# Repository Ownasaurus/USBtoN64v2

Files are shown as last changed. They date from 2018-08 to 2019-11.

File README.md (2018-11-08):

# USBtoN64v2
Utilizes STM32F446 on a Nucleo-F446RE with custom header or on a fully custom board for usb and n64 communication.

In this repository, you can find the latest version of the source code (TrueSTUDIO), 3D case (.stl), and PCB (Eagle .brd and .sch) files.

Currently supported USB devices:
- Keyboard
- Dualshock 3 Sixaxis
- Dualshock 4 v1 (with help from Kazon Wilson [kwilson21]) and v2
- Wireless Xbox 360 with Microsoft USB wireless receiver
- Wired Xbox 360
- Wired Xbox One

## Setting the controls:
1) Press the blue button on the Nucleo or the only button on the custom PCB. A new green LED (light) should light up solid when you go into "set controls" mode, and it should turn off when you finish setting the controls correctly.
2) Press the buttons in the appropriate order depending on which device is plugged in. For Xbox and PS, you also need to set range and deadzone. Please see below for instructions.
3) (optional) Press the same button again at any time to exit “set controls” mode early if you make a mistake.

### Xbox / Playstation:
DPAD_UP, DPAD_DOWN, DPAD_LEFT, DPAD_RIGHT, BUTTON_START, BUTTON_B, BUTTON_A, C_UP, C_DOWN, C_LEFT, C_RIGHT, BUTTON_L, BUTTON_R, BUTTON_Z

Next you set your RANGE. It starts at 100 by default.
Up (+) and Down (-) on the D-pad will increase or decrease the range by 5.
Right (+) and Left (-) on the D-pad will increase or decrease the range by 1.
The range cannot be greater than 100 or less than 0.
When you are done, hit "A" on the Xbox controller or "X" on the Playstation controller to move on.

Next you set your DEADZONE. It starts at 20 by default.
Up (+) and Down (-) on the D-pad will increase or decrease the deadzone by 5.
Right (+) and Left (-) on the D-pad will increase or decrease the deadzone by 1.
The deadzone cannot be greater than 100 or less than 0.
When you are done, hit "A" on the Xbox controller or "X" on the Playstation controller. Congratulations, you are done configuring your controls!

### KB:
A_UP, A_DOWN, A_LEFT, A_RIGHT, DPAD_UP, DPAD_DOWN, DPAD_LEFT, DPAD_RIGHT, BUTTON_START, BUTTON_B, BUTTON_A, C_UP, C_DOWN, C_LEFT, C_RIGHT, BUTTON_L, BUTTON_R, BUTTON_Z

Note that the device saves the controls even when the device is powered off. It saves the Xbox and Playstation controls together as a shared layout and the Keyboard controls separately.

## Updating the firmware:

### Nucleo (Prototype consisting of 2 connected boards)
Plug the device into a PC with a USB mini B cable, and drag&drop a .bin firmware file.

### v2 (one board in a case distributed only after 09/2018)
The v2 has a switch with two possible positions: "ON" or "1" (which is qutie confusing if you ask me).
- *The switch should be set to "1" for normal operation.*
- *The switch should be set to "ON" for firmware upgrade.*
- *The switch should be never be flipped while the device is powered to "ON" for firmware upgrade.*

So, first fip the switch to "ON". Plug the device into a PC with a USB mini B cable, and it should show up as a USB DFU device.
Use the "DfuSeDemo" software provided by STMicroelectronics to update the firmware with a .dfu file.
The "Dfu file manager" software is also provided alongside the "DfuSeDemo" by STMicroelectronics.
Then, unplug the device from the PC. Finally, flip the switch back "1".

## TODO:
- Complete LED support for PS4 (currently non-functional)
- Re-design PCB (and case) to be significantly smaller (in progress)

## Currently known bugs:
- None!

By: Ownasaurus

## Special thanks to:
????? ????? [Rainshifter] for help and support along the whole process

Kazon Wilson [kwilson21] for help with Dualshock 4 support

???? ????? [Serisium] for help with PCB design and understanding the STM32 hardware

Jeff Longo [?????] for help with PCB design and 3D case design

# Gamecube support - ALPHA
Gamecube support is currently in the experimental phase.
- If the data line and ground lines of a Gamecube cable are connected to the adapter, it should function.
- If BOTH N64 and Gamecube cables are attached, the device should be able to automatically detect which console is being used. The unused cable MUST be unplugged for proper functionality.
- Only XBOX controllers are currently supported.
- The controls are currently static and mimic the Gamecube controller layout.
- The sensitivity and deadzone are "borrowed" from the N64 controller settings.
- GC(X) / XBOX(B) button is currently un-mapped due to Rainshifter's preferences for bug testing.

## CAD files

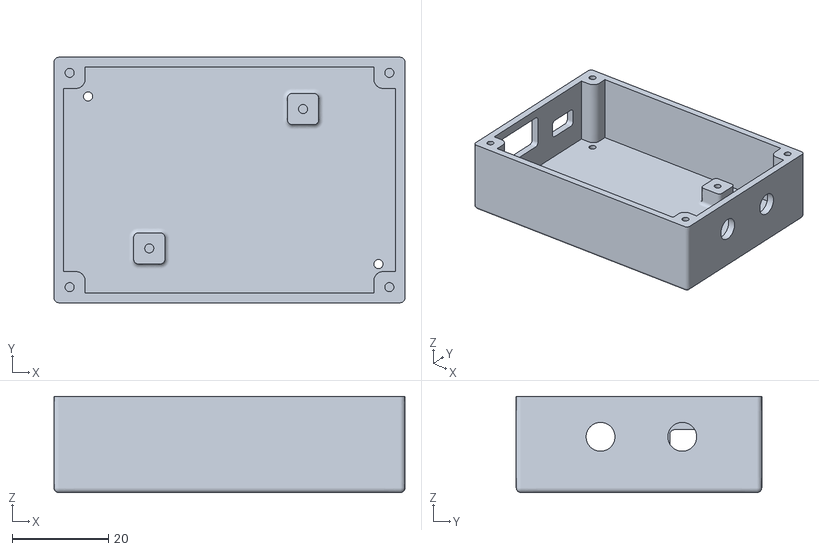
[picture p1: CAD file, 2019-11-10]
Custom Board/3D Case/small_bottom_case.stl
73.0 x 51.1 x 20.0

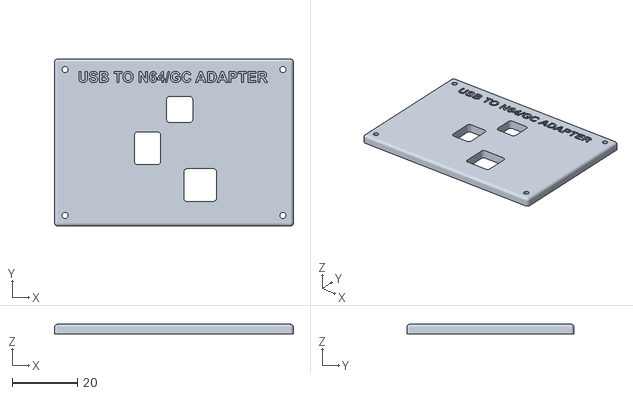
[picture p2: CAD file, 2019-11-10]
Custom Board/3D Case/small_top_case.stl
73.0 x 51.1 x 3.00

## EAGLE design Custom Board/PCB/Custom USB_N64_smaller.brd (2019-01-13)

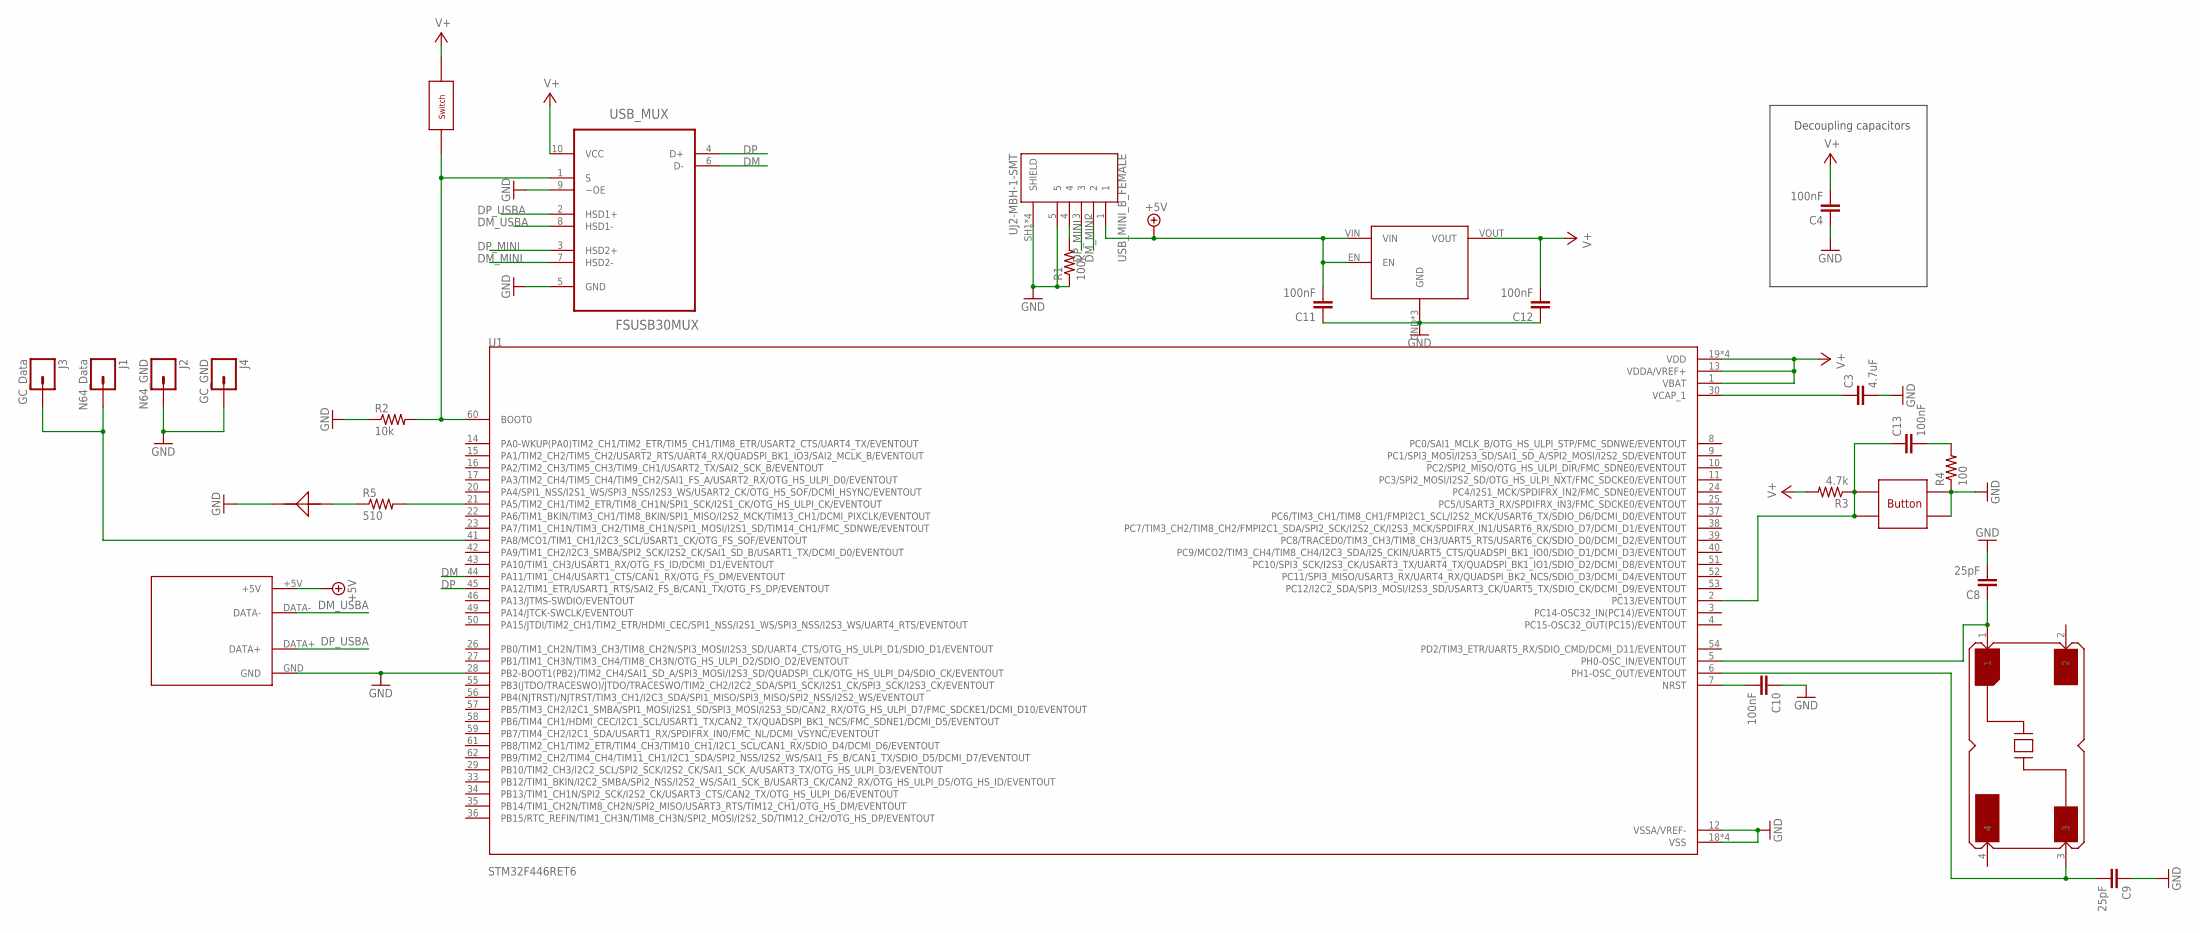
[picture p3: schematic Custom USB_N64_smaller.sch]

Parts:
C3: 4.7uF; C0805
C4, C10, C11, C12, C13: 100nF; C0805
C8, C9: 25pF; C0805
CHANGE_CONTROLS: PUSHBUTTON
J1: N64_Data; 1X01
J2: N64_GND; 1X01
J3: GC_Data; 1X01
J4: GC_GND; 1X01
R1: 100k; R0805
R2: 10k; R0805
R3: 4.7k; R0805
R4: 100; R0805
R5: 510; R0805
SWITCH: DM01
U1: STM32F446RET6; QFP50P1200X1200X160-64N
U$6: 17-21SYGC/S530-E2/TR8
USB_A_FEMALE: USB_A_F
USB_MINI_B_FEMALE: UJ2-MBH-1-SMT; CUI_UJ2-MBH-1-SMT
USB_MUX: FSUSB30MUX; SOP50P490X110-10N
V_REG: S-1172B33-U5T1G
XTAL_HSE: ABMM-8.000MHZ-B2-T; DFN-4

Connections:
3V3: C4.2, C12.2, R3.2, SWITCH.P$1, U1.1 (VBAT), U1.13 (VDDA/VREF+), U1.19 (VDD), U1.32 (VDD), U1.48 (VDD), U1.64 (VDD), USB_MUX.10 (VCC), V_REG.VOUT
+5V: C11.2, USB_A_FEMALE.+5V, USB_MINI_B_FEMALE.1, V_REG.EN, V_REG.VIN
DM: U1.44 (PA11/TIM1_CH4/USART1_CTS/CAN1_RX/OTG_FS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), USB_MUX.6 (D-)
DM_MINI: USB_MINI_B_FEMALE.2, USB_MUX.7 (HSD2-)
DM_USBA: USB_A_FEMALE.DATA-, USB_MUX.8 (HSD1-)
DP: U1.45 (PA12/TIM1_ETR/USART1_RTS/SAI2_FS_B/CAN1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), USB_MUX.4 (D+)
DP_MINI: USB_MINI_B_FEMALE.3, USB_MUX.3 (HSD2+)
DP_USBA: USB_A_FEMALE.DATA+, USB_MUX.2 (HSD1+)
GND: C3.2, C4.1, C8.2, C9.1, C10.1, C11.1, C12.1, CHANGE_CONTROLS.P$3, CHANGE_CONTROLS.P$4, J2.1, J4.1, R1.1, R2.1, R4.1, U1.12 (VSSA/VREF-), U1.18 (VSS), U1.28 (PB2-BOOT1(PB2)/TIM2_CH4/SAI1_SD_A/SPI3_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), U1.31 (VSS), U1.47 (VSS), U1.63 (VSS), U$6.NEG, USB_A_FEMALE.GND, USB_MINI_B_FEMALE.5, USB_MINI_B_FEMALE.SH1 (SHIELD), USB_MINI_B_FEMALE.SH2 (SHIELD), USB_MINI_B_FEMALE.SH3 (SHIELD), USB_MINI_B_FEMALE.SH4 (SHIELD), USB_MUX.5 (GND), USB_MUX.9 (~OE), V_REG.GND, V_REG.GND2 (GND), V_REG.GND3 (GND)
unnamed: R2.2, SWITCH.P$2, U1.60 (BOOT0), USB_MUX.1 (S)
unnamed: C10.2, U1.7 (NRST)
unnamed: C8.1, U1.5 (PH0-OSC_IN/EVENTOUT), XTAL_HSE.1
unnamed: C3.1, U1.30 (VCAP_1)
unnamed: C9.2, U1.6 (PH1-OSC_OUT/EVENTOUT), XTAL_HSE.3
unnamed: J1.1, J3.1, U1.41 (PA8/MCO1/TIM1_CH1/I2C3_SCL/USART1_CK/OT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)
unnamed: C13.1, CHANGE_CONTROLS.P$1, CHANGE_CONTROLS.P$2, R3.1, U1.2 (PC13/EVENTOUT)
unnamed: R5.2, U1.21 (PA5/TIM2_CH1/TIM2_ETR/TIM8_CH1N/SPI1_SC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)
unnamed: C13.2, R4.2
unnamed: R5.1, U$6.POS
unnamed: R1.2, USB_MINI_B_FEMALE.4

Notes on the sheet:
Decoupling capacitors

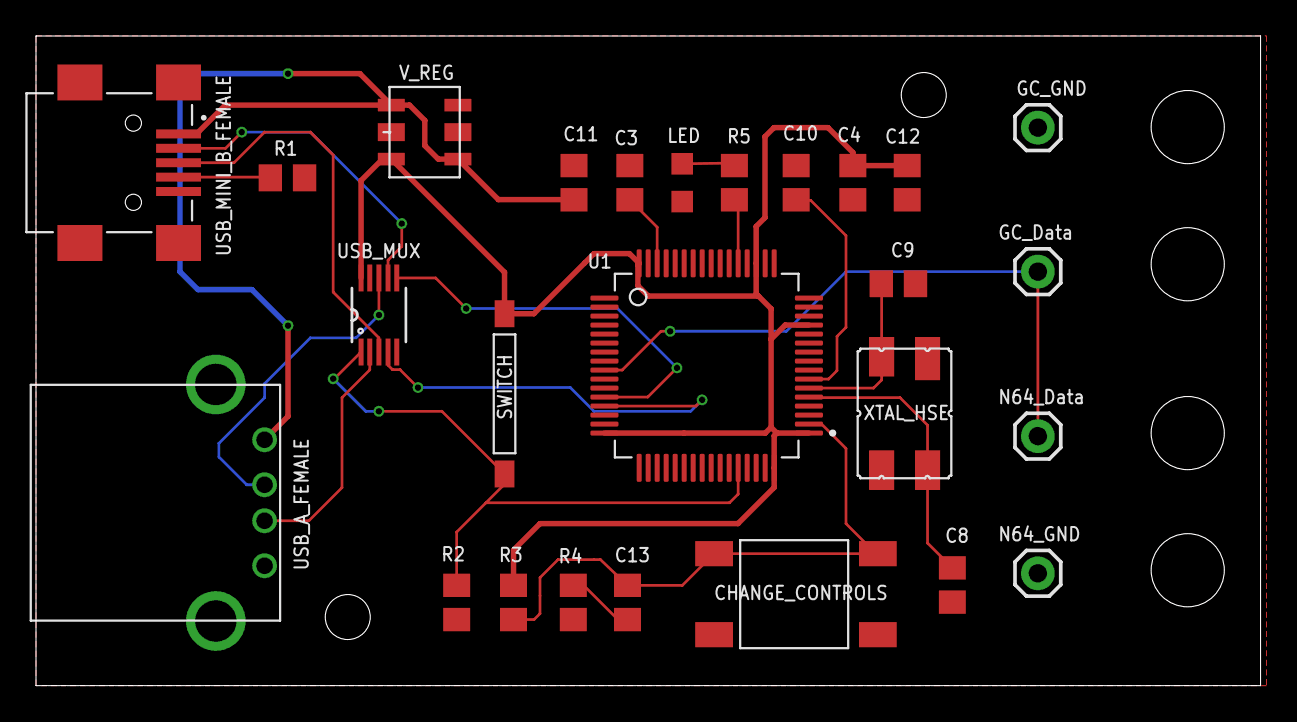
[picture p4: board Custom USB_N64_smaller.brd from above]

Board: 2 copper layers, 68.0 x 36.1 mm, 26 parts (0 on the bottom side), 20 nets.

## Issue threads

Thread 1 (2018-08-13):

Microsoft Wireless Xbox 360 randomly freezes and drops inputs

Ownasaurus, 2018-08-13:
Confirmed on 2 separate setups with 2 sets of hardware. Cause is currently unknown. Would LOVE a fix for this as it is the last major issue.

Ownasaurus, 2018-08-16:
Resolved in commit #25948df

Closed 2018-08-16.

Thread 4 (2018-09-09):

PS4 LED Support

Ownasaurus, 2018-09-09:
Not working yet. There's some code in there for it though.

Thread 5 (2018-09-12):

Add instructions on how to update the firmware

Ownasaurus, 2018-09-12:
Ensure to explain both the Nucelo process (drag&drop bin) and the custom PCB process (flip switch and DfuSe software)

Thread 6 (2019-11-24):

BUG: Setting N64 KB Controls

Ownasaurus, 2019-11-24:
After pressing the "set controls" button, It seems to sometimes ignore first button pressed, leading to an off-by-one when setting the controls.

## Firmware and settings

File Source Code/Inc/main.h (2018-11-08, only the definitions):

#define B1_Pin GPIO_PIN_13
#define B1_GPIO_Port GPIOC
#define USART_TX_Pin GPIO_PIN_2
#define USART_TX_GPIO_Port GPIOA
#define USART_RX_Pin GPIO_PIN_3
#define USART_RX_GPIO_Port GPIOA
#define LD2_Pin GPIO_PIN_5
#define LD2_GPIO_Port GPIOA
#define N64_DATA_Pin GPIO_PIN_8
#define N64_DATA_GPIO_Port GPIOA
#define N64_DATA_EXTI_IRQn EXTI9_5_IRQn
#define TMS_Pin GPIO_PIN_13
#define TMS_GPIO_Port GPIOA
#define TCK_Pin GPIO_PIN_14
#define TCK_GPIO_Port GPIOA
#define SWO_Pin GPIO_PIN_3
#define SWO_GPIO_Port GPIOB
#define tN 0.03921568627f //(10/255)
#define DEFAULT_RANGE 100
#define DEFAULT_DEADZONE 20
#define TRIGGER_THRESHOLD 5
#define XPAD_MAX 32767 // -32768 to +32767...
#define DS3_MAX 127

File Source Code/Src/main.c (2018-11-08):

// Ownasaurus
// rawr

/**
  ******************************************************************************
  * @file           : main.c
  * @brief          : Main program body
  ******************************************************************************
  * This notice applies to any and all portions of this file
  * that are not between comment pairs USER CODE BEGIN and
  * USER CODE END. Other portions of this file, whether 
  * inserted by the user or by software development tools
  * are owned by their respective copyright owners.
  *
  * Copyright (c) 2018 STMicroelectronics International N.V. 
  * All rights reserved.
  *
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
  ******************************************************************************
  */
/* Includes ------------------------------------------------------------------*/
#include "main.h"
#include "stm32f4xx_hal.h"
#include "stm32f4xx_hal_flash.h"
#include "stm32f4xx_hal_flash_ex.h"
#include "usb_host.h"

/* USER CODE BEGIN Includes */
#include <string.h>
#include "usbh_hid_ds3.h"

/* USER CODE END Includes */

UART_HandleTypeDef huart2;
uint8_t state = NORMAL;
#define SAVE_ADDR 0x08010000 // sector 4
Controls controls;
Controls* saveData = (Controls*)SAVE_ADDR;
uint8_t blueButtonPressed = 0;
ControllerType type = CONTROLLER_NONE;

/* USER CODE BEGIN PV */
N64ControllerData n64_data;
GCControllerData gc_data;
/* USER CODE END PV */

void SystemClock_Config(void);
static void MX_GPIO_Init(void);
static void MX_USART2_UART_Init(void);
void MX_USB_HOST_Process(void);

/* USER CODE BEGIN PFP */
void my_wait_us_asm(int n);

/* USER CODE END PFP */

/* USER CODE BEGIN 0 */

void ChangeButtonMappingKB(uint8_t bt)
{
    if(state == A_UP) // state = 1 --> analog up
    {
        controls.KBControls.KEYBOARD_a_up = bt;
    }
    else if(state == A_DOWN) // state = 2 --> analog up
    {
        controls.KBControls.KEYBOARD_a_down = bt;
    }
    else if(state == A_LEFT) // state = 3 --> analog up
    {
        controls.KBControls.KEYBOARD_a_left = bt;
    }
    else if(state == A_RIGHT) // state = 4 --> analog up
    {
        controls.KBControls.KEYBOARD_a_right = bt;
    }
    else if(state == DPAD_UP) // state = 5 --> dpad up
    {
        controls.KBControls.KEYBOARD_d_up = bt;
    }
    else if(state == DPAD_DOWN) // state = 6 --> dpad down
    {
        controls.KBControls.KEYBOARD_d_down = bt;
    }
    else if(state == DPAD_LEFT) // state = 7 --> dpad left
    {
        controls.KBControls.KEYBOARD_d_left = bt;
    }
    else if(state == DPAD_RIGHT) // state = 8 --> dpad right
    {
        controls.KBControls.KEYBOARD_d_right = bt;
    }
    else if(state == BUTTON_START) // state = 9 --> start
    {
        controls.KBControls.KEYBOARD_start = bt;
    }
    else if(state == BUTTON_B) // state = 10 --> B
    {
        controls.KBControls.KEYBOARD_b = bt;
    }
    else if(state == BUTTON_A) // state = 11 --> A
    {
        controls.KBControls.KEYBOARD_a = bt;
    }
    else if(state == C_UP) // state = 12 --> c up
    {
        controls.KBControls.KEYBOARD_c_up = bt;
    }
    else if(state == C_DOWN) // state = 13 --> c down
    {
        controls.KBControls.KEYBOARD_c_down = bt;
    }
    else if(state == C_LEFT) // state = 14 --> c left
    {
        controls.KBControls.KEYBOARD_c_left = bt;
    }
    else if(state == C_RIGHT) // state = 15 --> c right
    {
        controls.KBControls.KEYBOARD_c_right = bt;
    }
    else if(state == BUTTON_L) // state = 16 --> L
    {
        controls.KBControls.KEYBOARD_l = bt;
    }
    else if(state == BUTTON_R) // state = 17 --> R
    {
        controls.KBControls.KEYBOARD_r = bt;
    }
    else if(state == BUTTON_Z) // state = 18 --> Z
    {
        controls.KBControls.KEYBOARD_z = bt;
    }
}

void ChangeButtonMappingController(uint64_t bt)
{
    if(state == DPAD_UP) // state = 5 --> dpad up
    {
    	controls.XpadControls.up = bt;
    }
    else if(state == DPAD_DOWN) // state = 6 --> dpad down
    {
    	controls.XpadControls.down = bt;
    }
    else if(state == DPAD_LEFT) // state = 7 --> dpad left
    {
        controls.XpadControls.left = bt;
    }
    else if(state == DPAD_RIGHT) // state = 8 --> dpad right
    {
        controls.XpadControls.right = bt;
    }
    else if(state == BUTTON_START) // state = 9 --> start
    {
        controls.XpadControls.start = bt;
    }
    else if(state == BUTTON_B) // state = 10 --> B
    {
        controls.XpadControls.b = bt;
    }
    else if(state == BUTTON_A) // state = 11 --> A
    {
        controls.XpadControls.a = bt;
    }
    else if(state == C_UP) // state = 12 --> c up
    {
        controls.XpadControls.c_up = bt;
    }
    else if(state == C_DOWN) // state = 13 --> c down
    {
        controls.XpadControls.c_down = bt;
    }
    else if(state == C_LEFT) // state = 14 --> c left
    {
        controls.XpadControls.c_left = bt;
    }
    else if(state == C_RIGHT) // state = 15 --> c right
    {
        controls.XpadControls.c_right = bt;
    }
    else if(state == BUTTON_L) // state = 16 --> L
    {
        controls.XpadControls.l = bt;
    }
    else if(state == BUTTON_R) // state = 17 --> R
    {
        controls.XpadControls.r = bt;
    }
    else if(state == BUTTON_Z) // state = 18 --> Z
    {
        controls.XpadControls.z = bt;
    }
}

void SaveControls()
{
	HAL_FLASH_Unlock(); //unlock flash writing
	__HAL_FLASH_CLEAR_FLAG(FLASH_FLAG_EOP | FLASH_FLAG_OPERR | FLASH_FLAG_WRPERR |
                  FLASH_FLAG_PGAERR | FLASH_FLAG_PGPERR|FLASH_FLAG_PGSERR);
	FLASH_EraseInitTypeDef EraseInitStruct;
	EraseInitStruct.Sector = FLASH_SECTOR_4;
	EraseInitStruct.TypeErase = TYPEERASE_SECTORS;
	EraseInitStruct.VoltageRange = FLASH_VOLTAGE_RANGE_3;
	EraseInitStruct.NbSectors = 1;
	uint32_t SectorError = 0;
	if (HAL_FLASHEx_Erase(&EraseInitStruct, &SectorError) != HAL_OK) {
	    HAL_FLASH_Lock();
	    return;
	}

    uint32_t* data = (uint32_t*)&controls;

    // Total size is 114 bytes + 18 bytes = 132 bytes
    // Each word is 4 bytes, so the total size is 33 Words
    for(int ct = 0;ct < 33;ct++)
    {
    	HAL_FLASH_Program(FLASH_TYPEPROGRAM_WORD,SAVE_ADDR+(ct*4),*data); //each SAVE_ADDR+4 is 4 bytes because it is a memory address
        data++; // each data+1 is 4 bytes because it is a 32 bit data type
    }

    HAL_FLASH_Lock(); // lock it back up
}

void LoadControls()
{
    memcpy(&controls,saveData,sizeof(Controls));
}

void AdvanceState()
{
    state++;
    if((state == STATE_SENSITIVITY && type == CONTROLLER_KB) || state > STATE_DEADZONE) // we're done mapping the controls
    {
		SaveControls(); // write directly to flash
		state = NORMAL; // back to normal controller operation
    }
    else if(state == STATE_SENSITIVITY)
    {
    	controls.XpadControls.range = DEFAULT_RANGE;
    }
    else if(state == STATE_DEADZONE)
    {
    	controls.XpadControls.deadzone = DEFAULT_DEADZONE;
    }
}

uint8_t reverse(uint8_t b)
{
   b = (b & 0xF0) >> 4 | (b & 0x0F) << 4;
   b = (b & 0xCC) >> 2 | (b & 0x33) << 2;
   b = (b & 0xAA) >> 1 | (b & 0x55) << 1;
   return b;
}

void SetN64DataInputMode()
{
	// port A8 to input mode
	GPIOA->MODER &= ~(1 << 17);
	GPIOA->MODER &= ~(1 << 16);
}

void SetN64DataOutputMode()
{
	// port A8 to output mode
	GPIOA->MODER &= ~(1 << 17);
	GPIOA->MODER |= (1 << 16);
}

void write_1()
{
	GPIOA->BSRR = (1 << 24);
	my_wait_us_asm(1);
	GPIOA->BSRR = (1 << 8);
    my_wait_us_asm(3);
}

void write_0()
{
	GPIOA->BSRR = (1 << 24);
	my_wait_us_asm(3);
	GPIOA->BSRR = (1 << 8);
    my_wait_us_asm(1);
}

void SendStop()
{
	GPIOA->BSRR = (1 << 24);
	my_wait_us_asm(1);
	GPIOA->BSRR = (1 << 8);
}

// send a byte from LSB to MSB (proper serialization)
void SendByte(unsigned char b)
{
    for(int i = 0;i < 8;i++) // send all 8 bits, one at a time
    {
        if((b >> i) & 1)
        {
            write_1();
        }
        else
        {
            write_0();
        }
    }
}

void SendIdentityN64()
{
    // reply 0x05, 0x00, 0x02
    SendByte(0x05);
    SendByte(0x00);
    SendByte(0x02);
    SendStop();
}


void SendIdentityGC()
{
    SendByte(0x90);
    SendByte(0x00);
    SendByte(0x0C);
    SendStop();
}

void SendControllerDataN64()
{
    unsigned long data = *(unsigned long*)&n64_data;
    unsigned int size = sizeof(data) * 8; // should be 4 bytes * 8 = 32 bits

    for(unsigned int i = 0;i < size;i++)
    {
        if((data >> i) & 1)
        {
            write_1();
        }
        else
        {
            write_0();
        }
    }

    SendStop();
}

void SendControllerDataGC()
{
    uint64_t data = *(uint64_t*)&gc_data;
    unsigned int size = sizeof(data) * 8; // should be 8 bytes * 8 = 64 bits

    for(unsigned int i = 0;i < size;i++)
    {
        if((data >> i) & 1)
        {
            write_1();
        }
        else
        {
            write_0();
        }
    }

    SendStop();
}

void SendOriginGC()
{
	gc_data.a_x_axis = reverse(128);
	gc_data.a_y_axis = reverse(128);
	gc_data.c_x_axis = reverse(128);
	gc_data.c_y_axis = reverse(128);
	gc_data.l_trigger = 0;
	gc_data.r_trigger = 0;

	uint64_t data = *(uint64_t*)&gc_data;
	unsigned int size = sizeof(data) * 8; // should be 8 bytes * 8 = 64 bits

	for(unsigned int i = 0;i < size;i++)
	{
		if((data >> i) & 1)
		{
			write_1();
		}
		else
		{
			write_0();
		}
	}

	SendByte(0x00);
	SendByte(0x00);
	SendStop();
}

// 0 is 3 microseconds low followed by 1 microsecond high
// 1 is 1 microsecond low followed by 3 microseconds high
// if either of these while loops is going on 4us or more, break out of the function

uint8_t GetMiddleOfPulse()
{
	uint8_t ct = 0;
    // wait for line to go high
    while(1)
    {
        if(GPIOA->IDR & 0x0100) break;

        ct++;
        if(ct == 200) // failsafe limit TBD
        	return 5; // error code
    }

    ct = 0;

    // wait for line to go low
    while(1)
    {
        if(!(GPIOA->IDR & 0x0100)) break;

        ct++;
		if(ct == 200) // failsafe limit TBD
			return 5; // error code
    }

    // now we have the falling edge

    // wait 2 microseconds to be in the middle of the pulse, and read. high --> 1.  low --> 0.
    my_wait_us_asm(2);

    return (GPIOA->IDR & 0x0100) ? 1U : 0U;
}



uint32_t readCommand()
{
	uint8_t retVal;

	// we are already at the first falling edge
	// get middle of first pulse, 2us later
	my_wait_us_asm(2);
	uint32_t command = (GPIOA->IDR & 0x0100) ? 1U : 0U, bits_read = 1;

    while(1) // read at least 9 bits (1 byte + stop bit)
    {
        command = command << 1; // make room for the new bit
        retVal = GetMiddleOfPulse();
        if(retVal == 5) // timeout
        {
        	if(bits_read >= 8)
        	{
				command = command >> 2; // get rid of the stop bit AND the room we made for an additional bit
				return command;
        	}
        	else // there is no possible way this can be a real command
        	{
        		return 5; // dummy value
        	}
        }
        command += retVal;

        bits_read++;

        if(bits_read >= 25) // this is the longest known command length
        {
        	command = command >> 1; // get rid of the stop bit (which is always a 1)
        	return command;
        }
    }
}

/* USER CODE END 0 */

/**
  * @brief  The application entry point.
  *
  * @retval None
  */
int main(void)
{
  /* USER CODE BEGIN 1 */
  output_type = OUTPUT_UNDEFINED;
  memset(&n64_data,0,4); // clear controller state
  memset(&gc_data,0,8); // clear controller state
  gc_data.beginning_one = 1;
  LoadControls();

  /* USER CODE END 1 */

  /* MCU Configuration----------------------------------------------------------*/

  /* Reset of all peripherals, Initializes the Flash interface and the Systick. */
  HAL_Init();

  /* Configure the system clock */
  SystemClock_Config();

  /* Initialize all configured peripherals */
  MX_GPIO_Init();
  MX_USART2_UART_Init();
  MX_USB_HOST_Init();
  /* Infinite loop */
  /* USER CODE BEGIN WHILE */
  while (1)
  {

  /* USER CODE END WHILE */
	// check for button pressed to begin control re-map

	  if(state == NORMAL)
	  {
		  if(!(GPIOC->IDR & 0x2000)) // user wants to change controls
		  {
			  if(blueButtonPressed == 0) // make sure it's a separate button press
			  {

				  if(type == CONTROLLER_KB)
					  state = 1;
				  else if(type != CONTROLLER_NONE)
					  state = 5;

				  if(type != CONTROLLER_NONE)
				  {
					  // enter programming mode
					  GPIOA->BSRR = (1 << 5); // LED ON
					  blueButtonPressed = 1;
					  continue;
				  }
			  }
		  }
		  else
		  {
			  blueButtonPressed = 0;
		  }

		  MX_USB_HOST_Process();
	  }
	  else
	  {
		  if(!(GPIOC->IDR & 0x2000)) // user wants to cancel and return to regular mode
		  {
			  if(blueButtonPressed == 0) // make sure it's a separate button press
			  {
				  GPIOA->BSRR = (1 << 21); // LED OFF
				  blueButtonPressed = 1;
				  state = NORMAL;
				  continue;
			  }
		  }
		  else
		  {
			  blueButtonPressed = 0;
		  }

		  MX_USB_HOST_Process();

		  if(state == NORMAL) // about to return to normal operation, make sure the LED turns off
		  {
			  GPIOA->BSRR = (1 << 21); // LED OFF
			  blueButtonPressed = 0;
		  }
	  }

  /* USER CODE BEGIN 3 */

  }
  /* USER CODE END 3 */

}

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


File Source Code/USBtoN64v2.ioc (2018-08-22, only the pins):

Mcu.UserName=STM32F446RETx
PA11.Signal=USB_OTG_FS_DM
PA12.Signal=USB_OTG_FS_DP
PA13.GPIO_Label=TMS
PA13.Signal=SYS_JTMS-SWDIO
PA14.GPIO_Label=TCK
PA14.Signal=SYS_JTCK-SWCLK
PA2.GPIO_Label=USART_TX
PA2.Signal=USART2_TX
PA3.GPIO_Label=USART_RX
PA3.Signal=USART2_RX
PA5.GPIO_Label=LD2 [Green Led]
PA5.Signal=GPIO_Output
PA8.GPIO_Label=N64_DATA
PA8.Signal=GPXTI8
PA9.Signal=USB_OTG_FS_VBUS
PB3.GPIO_Label=SWO
PB3.Signal=SYS_JTDO-SWO
PC13.GPIO_Label=B1 [Blue PushButton]
PC13.Signal=GPXTI13
PC14-OSC32_IN.Signal=RCC_OSC32_IN
PC15-OSC32_OUT.Signal=RCC_OSC32_OUT
PC6.Signal=GPIO_Output
PH0-OSC_IN.Signal=RCC_OSC_IN
PH1-OSC_OUT.Signal=RCC_OSC_OUT

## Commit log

2018-08-05 Resolved n64 communication bugs. Skeleton code for XPAD.
    [main.c]
2018-08-07 works with wired x360
2018-08-12 xpad family supported, bug fixes, change xpad controls on the fly
    [main.c, main.h]
2018-08-13 fixed bug: xbox one triggers not functioning properly
    [main.c]
2018-08-13 All controller types can re-map button layout on-the-fly
2018-08-13 fixed ps3 led; updated readme; project is now in beta
2018-08-16 fixed wireless x360 issues
    [main.c, main.h]
2018-08-25 fixed ds3 controller, which apparently broke in a previous patch
    [main.c, main.h, usbh_conf.h]
2018-08-28 disabled unused pins to increase power efficiency
2018-09-09 re-organized project; added files for custom board
    [Custom USB_N64.brd, Custom USB_N64.sch, bottom_case.stl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]
2018-09-12 adding new, smaller board layout
    [Custom USB_N64_smaller.brd, Custom USB_N64_smaller.sch]
2018-09-12 fixed faulty V_REG foorprint and N64 silkscreen
    [Custom USB_N64.brd, Custom USB_N64.sch]
2018-09-24 updated custom case, improved window size and position
    [bottom_case.stl, top_case.stl]
2019-01-13 Updated custom board info
    [Custom USB_N64.brd, Custom USB_N64.sch, Custom USB_N64_smaller.brd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]
2019-11-10 major cleanup and fix static GC controls
    [small_bottom_case.stl, small_top_case.stl]

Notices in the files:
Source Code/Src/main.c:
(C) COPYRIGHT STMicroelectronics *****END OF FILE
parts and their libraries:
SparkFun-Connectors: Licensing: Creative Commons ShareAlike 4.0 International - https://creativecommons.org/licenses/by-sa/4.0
